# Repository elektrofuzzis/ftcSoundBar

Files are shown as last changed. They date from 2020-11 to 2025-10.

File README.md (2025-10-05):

# The ftcSoundBar Project

ftcSoundBar is a sound card for fischertechnik TXT4.0/TXT/TX-Controllers, Arduino, ftDuino and Raspeberry based on an [espressif LyraT](https://www.espressif.com/en/products/devkits/esp32-lyrat) board.

It has multiple connectors, so yit could be used in various configurations:
- wifi based WEB-UI
- wifi based RESTAPI
- I2C-bus Interface (TXT, TXT4.0)

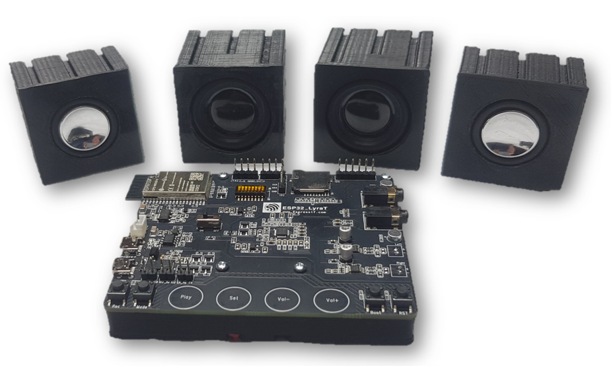
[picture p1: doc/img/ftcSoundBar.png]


*Please checkout the article about ftcSoundBar in [ft:pedia 4/2020](https://ftcommunity.de/ftpedia/2020/2020-4/ftpedia-2020-4.pdf#page=73") as well.*

## New version 1.4 available!

ftcSoundBar now supports TXT4.0-Controllers and RoboProCoding. Additionally, in I2C-mode the ftcSoundBar don't need a wifi any more.

## Quick start

In a first step, run the ftcSoundBar standalone - just playing some fancy musik.

ftcSoundBars's configuration and your musik files are stored on a SD card. Please format a SD Card as FAT32 and store some mp3-files in the root folder. Additionaly, please create a text file named ```ftcSoundBar.conf``` and store it in the root folder as well:

```
WIFI=1
WIFI_SSID=<SSID>
WIFI_PASSWORD=<Password>
TXT_AP_MODE=0
I2C_MODE=1
DEBUG=0
STARTUP_VOLUME=15
HOSTNAME=ftcSoundBar
```

Add your wifi's SSID and Password and plug the SD card in the ftcSoundBars SD card slot. 

Connect your speakers with the fischertechnik/Maerklin plugs at the right side of the device. Alternatively, you yould use headphones  at the ```PHONEJACK```.

There are two micro USB connectors ```POWER``` and ```UART``` at the left side of the board. Connect ```POWER``` to an USB charger - with at least 1A -.

The devices starts, the green LED between CPU and DIP switched will start flashing. After some seconds, flashing stops. Your device is now connected to your wifi.

*Notice: if your device don't stops flashing after some seconds, please check your SD-Card and wifi settings in your ftcSoundBar.conf file.*

Enter ```http://ftcSoundBar``` in your browser to access the webUI of the ftcSoundBar. Using the marked setup- and ftcSoundBar icons you can flip between the main and the configuration view:

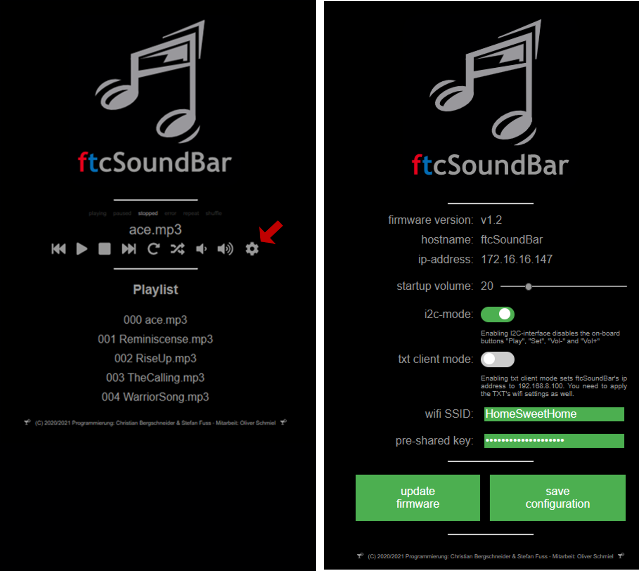
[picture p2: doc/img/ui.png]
main view


Try to play some songs on the main view.

*Notice: Maybe, you won't see the ```update firmware``` button in the configuration view. Don't worry  and read the firmware update section for more information.*

## Using your ftcSoundBar

Please check your prefreed controller and programm language. Follow up the links to get a short description how to use it.

| Controller | RoboProCoding | RoboPro | C++ | Phyton |
|:---:|:---:|:---:|:---:|:---:|
| TXT 4.0 | [i2c](./doc/ROBOProCoding-using-i2c-bus.md) | | | |
| TXT | | [i2c bus](./doc/ROBOPro-using-i²c-bus.md)<BR>[local wifi](./doc/ROBOPro-using-local-wifi.md)<BR>[TXT AP mode](./doc/ROBOPro-using-TXT's-AP-wifi-mode.md) | | [cfw](./doc/CFW-and-python-using-wifi.md) |
| TX | | [i2c bus](./doc/fischertechnik-TX.md) | | |
| ftDuino | | | [i2c bus](./doc/ftDuino.md) | |
| TX-PI | | | | [local wifi](./doc/TX-PI.md) |
| RaspberryPi | | | | [local wifi](./doc/Raspberry-Pi.md) |
| Arduino ATMEL | | | [i2c bus](./doc/ATMEL-based-Arduino-boards.md) | |
| ESP | | | [i2c bus](./doc/esp-32-family.md) | |

## Upgrade firmware

If you're upgrading the firmware the first time, please read the [firmware upgrade guide](./doc/Firmware-Upgrade.md).

Shortcut for experienced users:
- save `ftcSoundBar.bin` and `loader.bin`in the root folder of your SD card
- connect your ftcSoundBar to your local wifi
- Press `update firmware` button in the settings view

## Configuration File

| Option | Value | Description |
|:---:|:-----:|---|
| WIFI | 0..1 | 1 - use wifi | 0 - shutdown wifi |
| WIFI_SSID | <string> | SSID of your local wifi |
| WIFI_PASSWORD | <string> | Password of your local wifi |
| TXT_AP_MODE | 0..1 | In most cases 0<br>set it 1 to use the TXT AP option |
| I2C_MODE | 0..1 | 0 - off <br> 1 - on |
| DEBUG | 0..1 | In standard 0. 1 to get additional debug information in the console log. |
| STARTUP_VOLUME | 0..100 | Speaker volume after reseting the device. |
| HOSTNAME | <string> | Set a different hostname than ftcSoundBar. Just needed to run 2 devices in the same wifi |

## Build your own ftcSoundBar

This Chapter describes how to build up your own ftcSoundBar from scratch. If you prefer to work with a prebuild system, you could purchase one at [www.gundermann.org](http://www.gundermann.org/shop). If you have already a ftcSoundBar please continue with chapter 2.

- [Build Hardware](Build-your-own-ftcSoundBar-hardware)
- [Build Software](Build-the-software)

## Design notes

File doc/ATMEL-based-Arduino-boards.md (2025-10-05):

# Arduino using I2C and C++

Most Arduino controllers don't have a wifi card. So you need to work with i2C-bus. Since most of them are 5V controllers, you need to use a level shifter like [ftExtender](https://gundermann-software.de/produkt/ft-extender/) between your Ardiono and ftcSoundBar.

* Download `ftcSoundBar.zip` from this repo.
* Add this library to your Arduino IDE using Sketch/Include File/Add zip-library.
* Connect your Arduino's i2²c port with the 6 pin port of the ftExtender. Use a 1:1 ribbon cable to connect the 10 pin port of the ftExtender and ftcSoundBar. You could connect other i²c-devices with the same cable. Their bus addresses need to be different to 0x33, which is the ftcSoundBar's address.
* Checkout the example application via FILE/EXAMPLES/FTCSOUNDBAR/FTCSOUNDBARDUINO
* A detailed description of the Arduino API is described in ...

**Remarks:**
* See chapter 1 for a description of the ftcSoundBar's i²c connector.
* See ftExtender's documentation for a description of the i²c connectors.

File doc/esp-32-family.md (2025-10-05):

# ESP32 using i2c and C++

esp-32-controllers have an i²c-interface and an wifi interface as well. The actual implementation uses the i²c-inteface. But feel free to implement the wifi RESTapi.

* All GPIO-ports of your esp-32-controller could be used as i²C-interface. Connect SDA, SCL and GND with the ftcSoundBar i²c interface.
* You don't need a evel shifter, since both boards are based on 3.3V logic levels.
* Download `ftcSoundBar.zip` from this repo.
* Add this library to your Arduino IDE using Sketch/Include File/Add zip-library.
* You might add the correct SDA and SCL ports to the library.
* Checkout the example application via FILE/EXAMPLES/FTCSOUNDBAR/FTCSOUNDBARDUINO
* A detailed description of the Arduino API is described in ...

**Remarks:**
* See hardware description of the ftcSoundBar's i²c connector.

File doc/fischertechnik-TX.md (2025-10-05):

# TXT with ROBOPro using a I2C cable

The fischertechnik TX controller doesn't have a wifi card. So you need to work with a ribbon cable. Since TX is a 5V controller, you need to use a level shifter like [ftExtender](https://gundermann-software.de/produkt/ft-extender/) between TX and ftcSoundBar.

- Checkout `robopro` folder
- Try `ftcSoundBar_I2C_Example.rpp` to play some songs.
- Store `robopro/lib/ftcSoundBarI2C.rpp` in your ROBOPro's library folder, so you could use it in your own project.

*MAC-Users: `ftcSoundBarI2C.rpp` is working fine with Parallels and Wine.*.

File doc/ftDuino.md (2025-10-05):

# ftDuino using I2C and C++

The ftDuino controller doesn't have a wifi card. So you need to work with i2C-bus. Since ftDuino is a 5V controller, you need to use a level shifter like [ftExtender](https://gundermann-software.de/produkt/ft-extender/) etween ftDuino and ftcSoundBar.

* Download `ftcSoundBar.zip` from this repo.
* Add this library to your Arduino IDE using Sketch/Include File/Add zip-library.
* Connect ftDuino's i2²c port with the ftExtender using a 1:1 ribbon cable. Use another 1:1 ribbon cable to connect ftExtender and ftcSoundBar. You could connect other i²c-devices with the same cable. Their bus addresses need to be different to 0x33, which is the ftcSoundBar's address.
* Checkout the example application via FILE/EXAMPLES/FTCSOUNDBAR/FTCSOUNDBARDUINO
* A detailed description of the Arduino API is described in ...

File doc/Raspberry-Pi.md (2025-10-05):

# Raspberry PI using wifi & Phyton

Raspberry Pi users could use the python interface to program the ftcSoundBar:

* Download phython library fom this repo.
* Connect TX-PI and ftcSoundBar to your local wifi.
* Use the python library to write your code.

**Remarks:**

* The library is very general. So it's working fine on every computer, which has a wifi connection and a python Intepreter.
* The raspberry pi has a i²c-bus-interface. You could use this interface, too. But you need to implement the i²c api on your own.

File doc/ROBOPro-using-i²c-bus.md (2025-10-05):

# TXT controller using roboPro & I2C

To connect the ftcSoundBar via i²c-bus, you just need to connect a 1:1 ribbon cable between TXT extention port and ftcSoundBar's I2C interface at the right side. 

- Checkout `robopro` folder
- Try `ftcSoundBar_I2C_Example.rpp` to play some songs.
- Store `robopro/lib/ftcSoundBarI2C.rpp` in your ROBOPro's library folder, so you could use it in your own project.

*MAC-Users: `ftcSoundBarI2C.rpp` is working fine with Parallels and Wine.*

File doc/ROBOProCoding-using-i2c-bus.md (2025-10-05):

# TXT 4.0 controller using ROBOProCoding & I2C

To connect the ftcSoundBar via i²c-bus, you need [6-to-pin-adapter](https://www.fischerfriendswoman.de/index.php?p=7&sp=9#R7668al) and two 1:1 ribbon cables between TXT 4.0 extention port and ftcSoundBar's I2C interface at the right side. 

- Checkout `RoboProCoding` folder
- Try `ftcSoundBar.ft` to play some songs.

*The getter functions like getVolume are not stable, due to some I2C bus limitations in the used expressif framework. As a workaoud, you could store the last transferred value in a global variable and use it instead of calling the getter functions.*

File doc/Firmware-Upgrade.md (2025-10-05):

# Firmware Upgrade Guide

## Prerequisites

Download the files ftcSoundBar.bin and Loader.bin from GitHub.

Store both files on you ftcSoundBar's SD card.

Configure ftcSoundBar.conf to use wifi:

```
WIFI=1
WIFI_SSID=<SSID>
WIFI_PASSWORD=<Password>
TXT_AP_MODE=0
I2C_MODE=1
DEBUG=0
STARTUP_VOLUME=15
HOSTNAME=ftcSoundBar
```
Check the following parameters

- WIFI=1 - This parameter is new in version 1.4
- Fill WIFI_SSID with your wifi's name.
- Fill WIFI_PASSWORD with your wifi's password.
- TXT_AP_MODE=0
- HOSTNAME=ftcSoundBar

## Run the Upgrades

Plug the SD card  in your ftcSoundBar and press RESET.
Once the grenn LED stops blinking, the ftcSoundBar has connected to your wifi.
Enter ```http:\\ftcSoundBar``` in your browser:

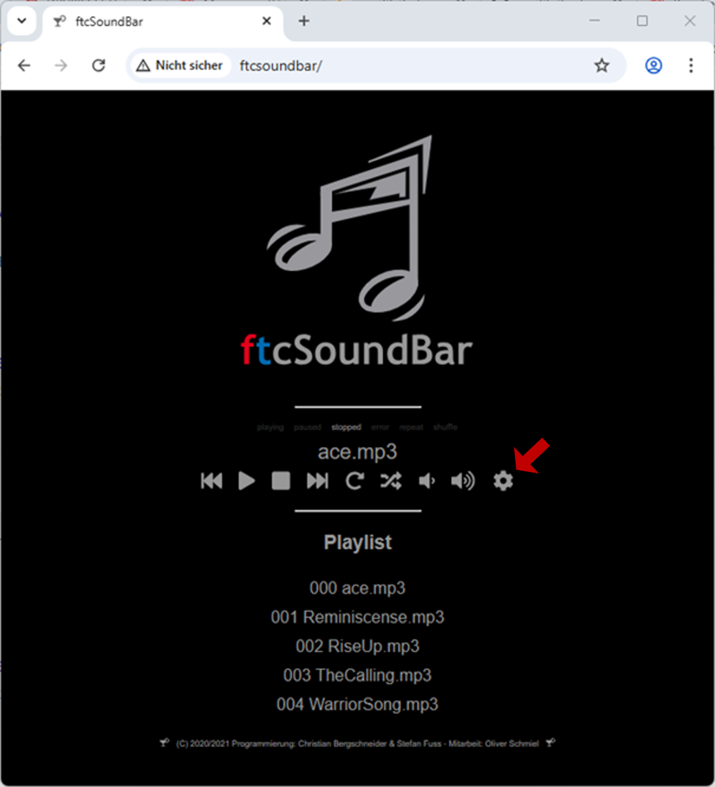
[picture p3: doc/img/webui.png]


Click the marked setup-button to change to the setup view:

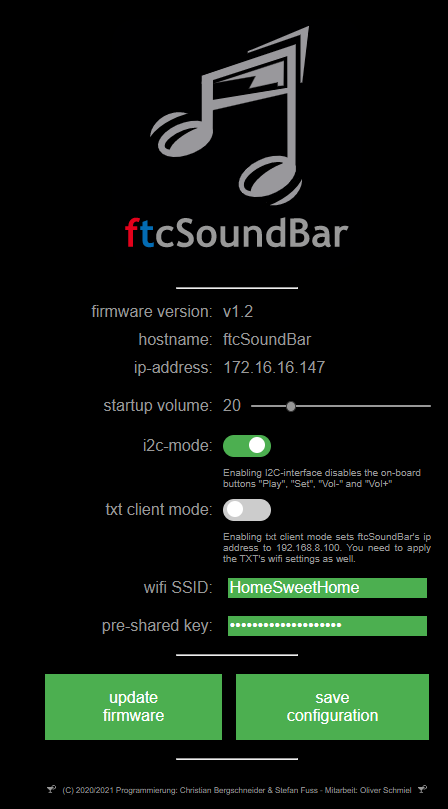
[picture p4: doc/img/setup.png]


With ```upgrade firmware``` you could now start the upgrade process.

During the upgrade, the green led flashes. Once it stops flashing, the firmware upgrade process succeeded. You could now call enter the ftcSoundBar in your browser again. Check the version number at the setup view.

*If you are missing the upgrade button, please check if both binary files ftcSoundBar.bin and loader.bin are stored at the SD card.*

## Follow up the upgrade porocess

Connect a USB cable to the UART port. You will now identify a new serial port at your PC.

Start a terminal program like putty and connect your serial interface with 115.200 Baud.

With clicking the update button, the process starts. In a first step ```loader.bin``` is flashed to the second partition:

```
I (25820) ftcSoundBar: Running partition type 0 subtype 16 (offset 0x00100000)
I (25830) ftcSoundBar: Writing to partition subtype 17 at offset 0x3b0000
I (25840) ftcSoundBar: data_read=1024
I (25850) ftcSoundBar: New firmware version: V1.31-dirty
I (25850) ftcSoundBar: Running firmware version: V1.31-dirty
I (26320) ftcSoundBar: esp_ota_begin succeeded
I (26340) ftcSoundBar: data_read=1024
I (26350) ftcSoundBar: data_read=1024

...

I (30130) ftcSoundBar: data_read=0
I (30130) ftcSoundBar: Total Write binary data length: 309760
I (30130) esp_image: segment 0: paddr=003b0020 vaddr=3f400020 size=11248h ( 70216) map
I (30170) esp_image: segment 1: paddr=003c1270 vaddr=3ffb0000 size=028f8h ( 10488)
I (30180) esp_image: segment 2: paddr=003c3b70 vaddr=40080000 size=0c4a8h ( 50344)
I (30210) esp_image: segment 3: paddr=003d0020 vaddr=400d0020 size=27b58h (162648) map
I (30280) esp_image: segment 4: paddr=003f7b80 vaddr=4008c4a8 size=03e5ch ( 15964)
I (30290) esp_image: segment 0: paddr=003b0020 vaddr=3f400020 size=11248h ( 70216) map
I (30330) esp_image: segment 1: paddr=003c1270 vaddr=3ffb0000 size=028f8h ( 10488)
I (30350) esp_image: segment 2: paddr=003c3b70 vaddr=40080000 size=0c4a8h ( 50344)
I (30370) esp_image: segment 3: paddr=003d0020 vaddr=400d0020 size=27b58h (162648) map
I (30440) esp_image: segment 4: paddr=003f7b80 vaddr=4008c4a8 size=03e5ch ( 15964)
I (30510) ftcSoundBar: Flashing firmware succeded.
I (30510) ftcSoundBar: Rebooting system in 5s
```

The loader now flashed the ftcSoundBar firmware to the other partition:

```
I (390) ftcSoundBar flash loader: **********************************************************************************************
I (400) ftcSoundBar flash loader: *                                                                                            *
I (410) ftcSoundBar flash loader: *                    Asymetric bootloader for flashing ftcSoundBar.bin.                      *
I (420) ftcSoundBar flash loader: *             (C) 2021 Oliver Schmiel, Christian Bergschneider & Stefan Fuss                 *
I (430) ftcSoundBar flash loader: *                                        Version v1.21                                       *
I (440) ftcSoundBar flash loader: *                                                                                            *
I (460) ftcSoundBar flash loader: * -> PLEASE BE PATIENT DRUING FLASH PROCESS. DON'T UNPLUG YOUR FTCSOUNDBAR UNTIL NOTICED! <- *
I (470) ftcSoundBar flash loader: *                                                                                            *
I (480) ftcSoundBar flash loader: **********************************************************************************************
I (490) ftcSoundBar flash loader:
I (500) ftcSoundBar flash loader: [1.0] Initialize peripherals management
I (510) ftcSoundBar flash loader: [1.1] Initialize and start peripherals
E (510) gpio: gpio_pullup_en(80): GPIO number error (input-only pad has no internal PU)
I (520) SDCARD: Using 1-line SD mode,  base path=/sdcard
I (530) AUDIO_THREAD: The esp_periph task allocate stack on internal memory
I (590) SDCARD: CID name SU02G!

I (1030) gpio: GPIO[22]| InputEn: 0| OutputEn: 0| OpenDrain: 0| Pullup: 1| Pulldown: 0| Intr:0
I (1030) ftcSoundBar flash loader: [2.0] Start flashing firmware
I (1030) ftcSoundBar flash loader: Running partition type 0 subtype 17 (offset 0x003b0000)
I (1040) ftcSoundBar flash loader: Writing to partition subtype 16 at offset 0x100000
I (1060) ftcSoundBar flash loader: data_read=1024
I (1060) ftcSoundBar flash loader: New firmware version: V1.31-dirty
I (1070) ftcSoundBar flash loader: Running firmware version: V1.31-dirty
I (3910) ftcSoundBar flash loader: esp_ota_begin succeeded
I (3930) ftcSoundBar flash loader: data_read=1024

...

I (21230) ftcSoundBar flash loader: data_read=0
I (21230) ftcSoundBar flash loader: Total Write binary data length: 1264224
I (21230) esp_image: segment 0: paddr=00100020 vaddr=3f400020 size=43ca8h (277672) map
I (21330) esp_image: segment 1: paddr=00143cd0 vaddr=3ffb0000 size=04344h ( 17220)
I (21340) esp_image: segment 2: paddr=0014801c vaddr=40080000 size=07ffch ( 32764)
I (21350) esp_image: segment 3: paddr=00150020 vaddr=400d0020 size=d2b04h (862980) map
I (21630) esp_image: segment 4: paddr=00222b2c vaddr=40087ffc size=11f08h ( 73480)
I (21660) esp_image: segment 0: paddr=00100020 vaddr=3f400020 size=43ca8h (277672) map
I (21750) esp_image: segment 1: paddr=00143cd0 vaddr=3ffb0000 size=04344h ( 17220)
I (21760) esp_image: segment 2: paddr=0014801c vaddr=40080000 size=07ffch ( 32764)
I (21780) esp_image: segment 3: paddr=00150020 vaddr=400d0020 size=d2b04h (862980) map
I (22060) esp_image: segment 4: paddr=00222b2c vaddr=40087ffc size=11f08h ( 73480)
I (22140) ftcSoundBar flash loader: Flashing firmware succeded.
I (22140) ftcSoundBar flash loader: Rebooting system in 5s
```

Afterwards the new firmware starts.

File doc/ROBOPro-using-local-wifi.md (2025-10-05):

# TXT with ROBOPro using a local wifi connection

In this configuration, you use the local wifi to send commands from your TXT controller to the ftcSoundBar. Since you already connected the ftcSoundBar to your local wifi during setup, it's a very simple way to program the ftcSoundBar. 

The wifi connection is nice, if you are working on a bigger projekt, because you don't need any cabling between TXT and ftcSoundBar at all.

**a) upload libftcSoundBar.so on your TXT controller**

First, you need to upload the `libftcSoundBar.so` library to your TXT controller. 
* Connect your TXT controller to your local wifi network using client mode (SETTINGS/NETWORK/WLAN/WLAN MODE/WLAN-CLIENT).
* Enable SSH DAEMON and WEB SERVER on your TXT controller (SETTINGS/SECURITY).
* Reboot your TXT controller.
* Start a browser and enter the TXT's IP address to connect to TXT's web server.
* The TXT will ask for simple authentification. Username is ROBOPro and and password is your TXT's serial number.
* The web site will display a directoy. Choose folder `libs`.
* Use button `upload files` to upload `libftcSoundBar.so` library into the `libs` folder.

If you get an write error while uploading the library, you need to change some rights on your TXT controller. This is a bug, dependend on your TXT's firmware version. You need to change the rights only one time:
* Connect to your TXT controller using a ssh client like  [putty](https://www.putty.org/).
* Username is ROBOPro, password is ROBOPro, too.
* Run `chmod 744 /opt/knobloch/libs`.

The step uploading the library is a little bit tricky. But never mind, you need to repeat this step after deploying a new firmware version only.

**b) Check ftcSoundBar**

* Connect the ftcSoundBar to your local wifi network as described in chapter 2.
* Use [http://ftcSoundBar](http://ftcSoundBar) to checkout your sound files track numbers. Since ROBOPro isn't able to handle strings, you need the track numbers to write your code.

**c) Working with ROBOPro**

* Download ftcSoundBarWifi.rpp and store it in your ROBOPro's library folder.
* Checkout the ROBOPro examples ftcSoundBarPlayer.rpp and ftcSoundBar_wifi_Example1.rpp
* A detailed description of the ROBOPro API is described in ...

The ROBOPro library is just a facade of the shared library `libftcSoundBar.so`. In standard wifi configuration, the library tries to access ftcSoundBar using it's DNS name `ftcSoundBar`, which is resolved by mDNS from the ftcSoundBar itself. Since TXT is connected to your local wifi and you already managed to access the ftcSoundBar's WEB UI, this procedure is very robust.

This procedure will fail, if ftcSoundBar and TXT controler are not connected to the same IP segment. In this case add the ftcSoundBar's ip-address to your local DNS controller or use the IP-commands in the robopro library.

**Remarks**

* MAC-Users: Please be aware, there a some limitations in using ROBOPro on a MAC. Wine won't work with this configuration at all, Parallels is fine but a little bit slow.
* Working with USB cable: You could connect your PC with the TXT using a USB cable as well. The TXT is able to be connected to multiple networks at on time (wifi to access ftcSoundBar and USB to conect to ROBOPro).
* Offline Mode is working fine, too.

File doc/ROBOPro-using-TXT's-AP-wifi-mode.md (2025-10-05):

# TXT with ROBOPro using a TXT in AP mode

Using the TXT's AP wifi mode is nearby the same procedure as using local wifi. The advantage of this mode is running your model on an exhibition or convention; you don't need any public wifi infrastructure.

* upload the library `libftcSoundBar.so` as described in 3.2.1.
* Change your TXT wifi settings to AP MODE.
* Connect to your ftcSoundBar's setup page, activate switch "TXT Client Mode", set TXT's SSID & password and save configuration.

Now you could access the ftcSoundBar from your TXT using the TXT's AP Mode. Please keep in mind, that you can't access to the WEB-UI of the ftcSoundBar from your PC any more. To access it, you need to connect your notebook to the TXT wifi, too. Since you might not get an ip-address assigned autmatically, you might setup a static ip-address on your PCs wifi card.

To connect the TXT from your PC, it's helpful to use the USB cable.

The ROBOPro library is the same as in local wifi mode. So all of your ROBOPro programs working in local wifi mode will run in AP mode, too.

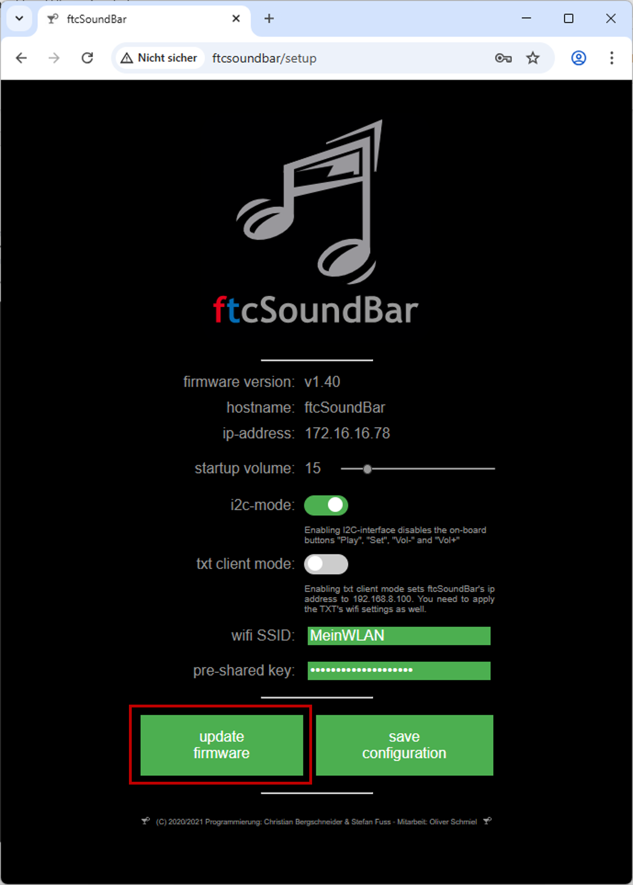
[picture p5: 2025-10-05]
doc/img/upgrade.png

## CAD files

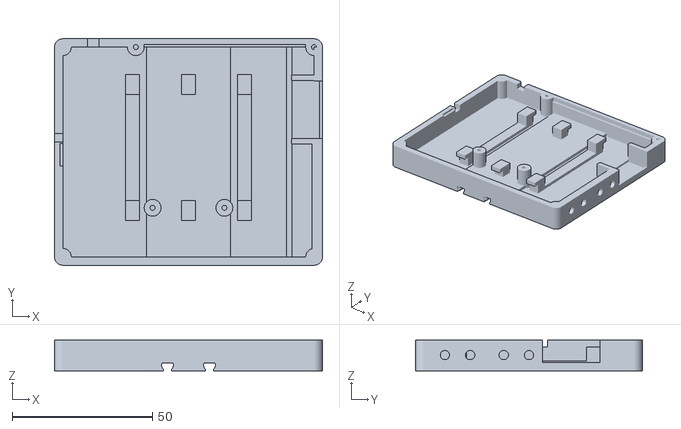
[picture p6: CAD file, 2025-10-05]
3D/ftcSoundBar_6v1a.stl
95.6 x 80.8 x 11.0

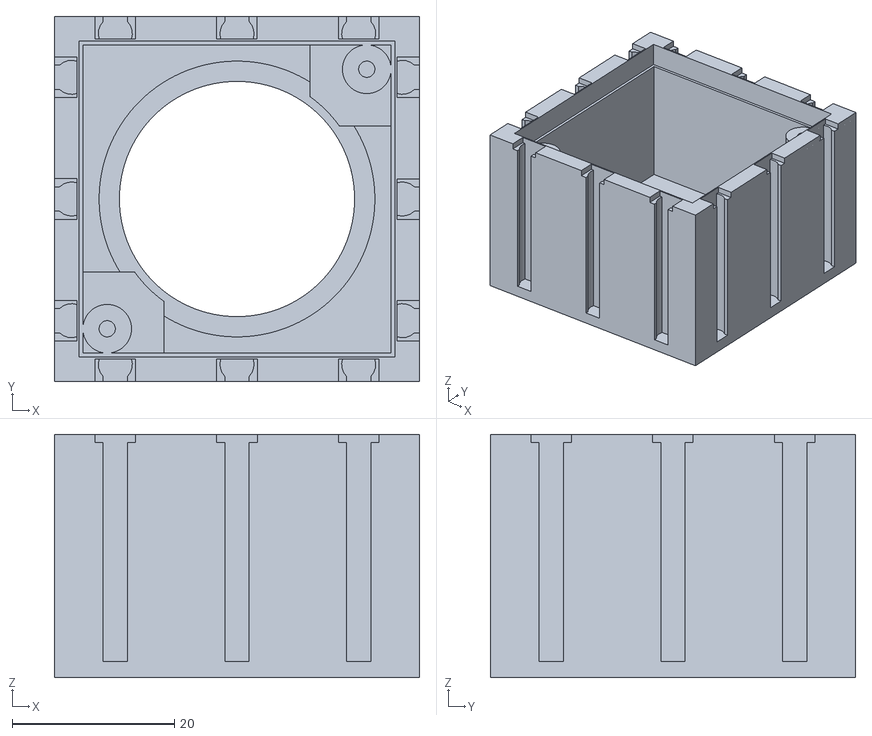
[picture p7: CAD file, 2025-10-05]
3D/box_pui_AS03104MR-N50-R_v14.stl
45.0 x 45.0 x 30.0

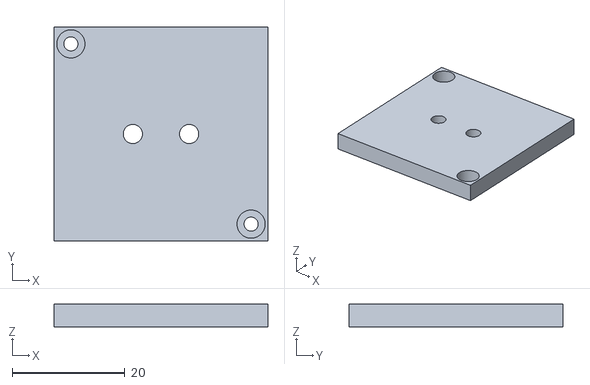
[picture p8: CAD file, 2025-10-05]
3D/box_rear_cover1v2.stl
38.0 x 38.0 x 4.00

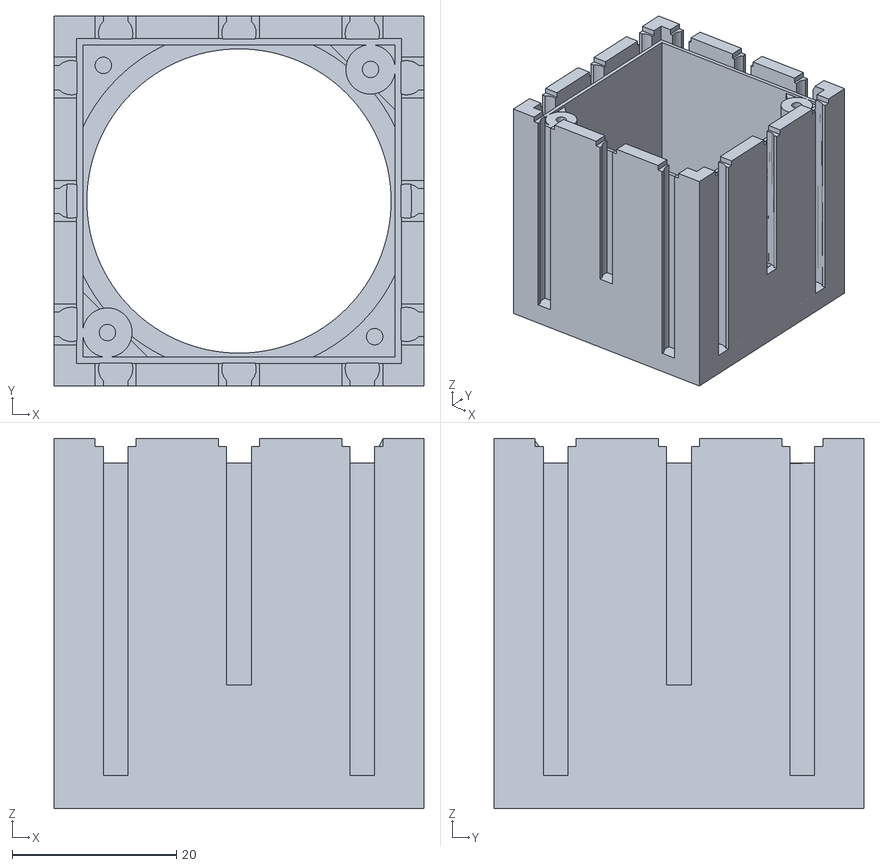
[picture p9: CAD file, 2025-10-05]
3D/box_gikfun_EK1794.stl
45.0 x 45.0 x 45.0

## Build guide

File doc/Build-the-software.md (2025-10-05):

# Build the Software

If you don't want, you don't need to build the software by your own. In every release, you could download the needed prebuild files.

The following text describes how to build your own release.

## ftcSoundBar's firmware

To flash the ftcSoundBar firmware the first time, you need to install some tools on your PC.

1. `git clone -b v5.2 https://github.com/espressif/esp-idf.git`
2. `cd esp-idf`
3. run `install.bat` on windows systems or `install.sh` on linux distributions
4. `git clone -b v2.7 https://github.com/espressif/esp-adf.git`
5. set in esp-idf/export.bat on windows Systems or export.sh on linux systems the variable ADF_PATH. Use the path, where you installed espadf.
6. `git clone https://github.com/elektrofuzzis/ftcSoundBar.git`
7. run `esp-idf/export.bat` or `esp-idf/export.sh` dependend on your OS.
8. `cd ftcSoundBar/firmware`
9. `idf.py build`
10. `idf.py flash`

## .so-library - TXT controller only

1. Download and install gcc compiler arm-linux-gnueabihf from <a href="https://www.linaro.org/downloads/">linareo<a>
2. `arm-linux-gnueabihf-gcc.exe -Ilib\gcc\arm-linux-gnueabihf\4.9.1\include -c -fpic -Wall libftcSoundBar.cpp`
3. `arm-linux-gnueabihf-gcc.exe -Ilib\gcc\arm-linux-gnueabihf\4.9.1\include -shared libftcSoundBar.o`

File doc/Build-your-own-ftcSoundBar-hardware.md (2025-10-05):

# Build your own Hardware

To build your own ftcSoundBar, you need a 3D printer and a soldering iron. If you don't have the needed equipment, you can purchase your ftcSoundBar at <a href="www.gundermann.org">http://www.gundermann.org/shop<a>

First, you need to organzize some components:
* 1 x <a href="https://www.espressif.com/en/products/devkits/esp32-lyrat">espressif LyraT</a>.
* 2 x <a href="https://www.puiaudio.com/products/as03104mr-n50-r">PUI audio speakers AS03104MR-N50-R</a>
* 1 x <a href="https://www.amphenol-icc.com/quickie-66506001lf.html">pin header / wire to board connecttor 10 positions"</a>
* 10 x tapping screws 2,2 x 4,5 mm
* 8 x <a href="https://www.fischerfriendswoman.de/index.php?p=7&sp=3#R7144">Bundhülse 8.4mm</a>
* 4 x cables with 2 cords (loud speakers)
* 1 x cable with 3 cords (i²c interface)

Download and print <a href="https://www.thingiverse.com/thing:4691172">speaker and ftcSoundBar case</a> at thingiverse

## ftcSoundBar

The lyraT board needs some simple modifications to get the I²C-connector and loud speaker connectors to the right side of the case:

<table>
<tr >
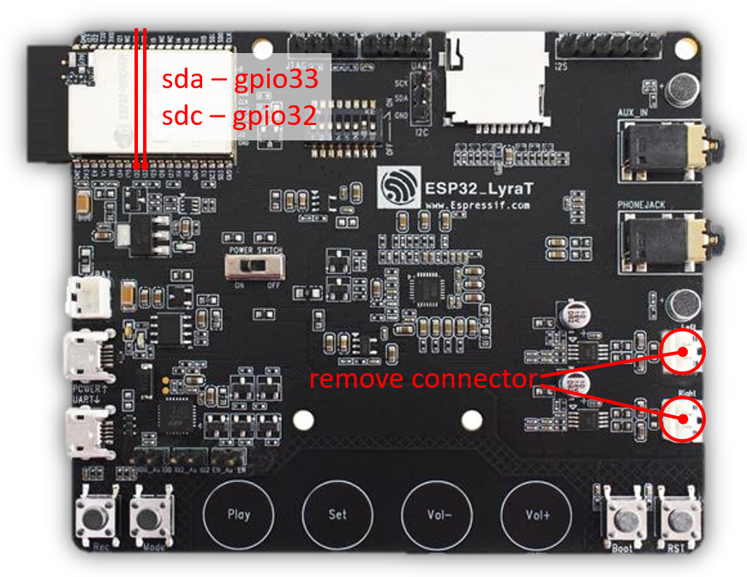
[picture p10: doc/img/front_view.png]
<td width="50%" height="300px"></td>
<td>At the front side of your LyraT board you need to remove the speaker connectors.<br><br>Add two cords of the i²c cable to GPIO32 and GPIO33 directly at the esp32-processor and fix it with some hot glue. The cables will be connected to the 10pos pin header in the ftcSoundBar case.</td></tr>

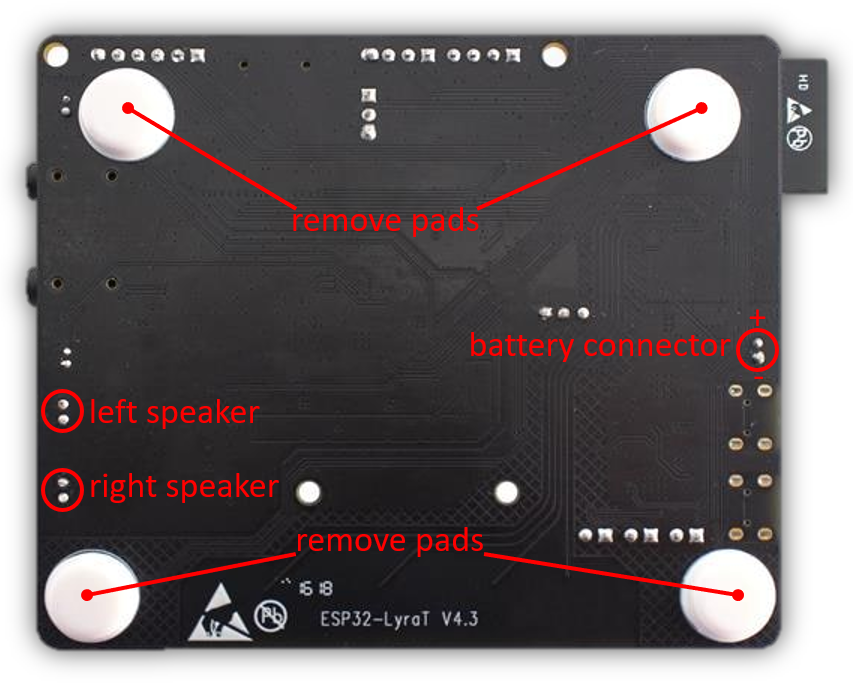
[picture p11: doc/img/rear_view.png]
<tr><td width="50%" height="300px"></td><td>Remove the 4 pads.<br><br>Add 2 loud speaker cables from the rear side to connect to the "Bundhülse" which will be glued in the ftcSoundBar case.<br><br>Connect the last cord of the i²c cable to the "-" pin of the battery connector.</td> </tr>

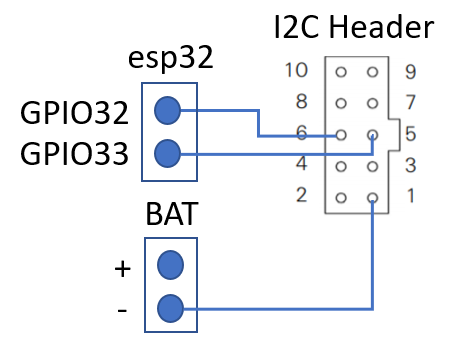
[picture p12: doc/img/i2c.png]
<tr><td width="50%" height="300px"></td>
<td>Connect the i²c cable to the 10 pos pin header as shown on the left side.<br><br>The pin header is compliant with the 3.3V fischertechnik-TXT extention port - pin 1 GND, pin 5 SDA, pin 6 SCL.
</td></tr>

</table>

## Speaker box

Setting up the boxes is quite easy:
* Connect a 2 cords cable to the loud speaker. 
* Plug two "Bundhülse" into the mounting pad and solder the cords.
* Set the loud speaker in the case by turning it to the left.
* Tight the mounting plate with a screw to the rear cap.
* Screw the rear cap with the box case.

<table>
<tr>
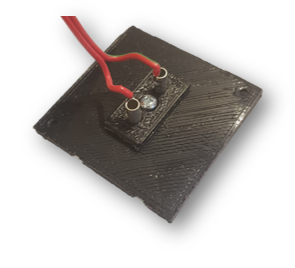
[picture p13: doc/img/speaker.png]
<td height="300px"></td>
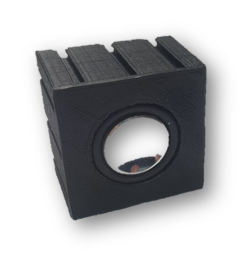
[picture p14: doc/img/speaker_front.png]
<td></td>
</tr>
</table>

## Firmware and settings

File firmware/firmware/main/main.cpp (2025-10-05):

/****************************************************************************************
 *
 * ftcSoundBar - a LyraT based fischertechnik compatible music box.
 *
 * Version 1.3
 *
 * (C) 2020 Oliver Schmied, Christian Bergschneider & Stefan Fuss
 *
 * Please run idf.py menuconfig, first
 *
 * EXAMPLE-CONFIGURATION: setting SSID & Password is helpful, but not mandatory
 * COMPONENT-CONFIGURATION/FAT FILESYSTEM SUPPORT: long filename support, UTF 8 encoding
 *
 ****************************************************************************************/

#define LOG_LOCAL_LEVEL ESP_LOG_DEBUG

#include <esp_wifi.h>
#include <esp_event.h>
#include <nvs_flash.h>
#include <esp_log.h>
#include <audio_element.h>
#include <esp_flash_partitions.h>
#include <esp_partition.h>
#include <esp_ota_ops.h>
#include <freertos/FreeRTOS.h>
#include <freertos/task.h>
#include <freertos/event_groups.h>
#include <input_key_service.h>
#include <string.h>
#include <sys/param.h>
#include <sys/unistd.h>
#include <esp_vfs.h>
#include <esp_http_server.h>
#include <cJSON.h>
#include <stdbool.h>
#include <mdns.h>
#include <esp_netif.h>
#include <periph_wifi.h>
#include <esp_task_wdt.h>

#include "adfcorrections.h"
#include "playlist.h"
#include "pipeline.h"
#include "ftcSoundBar.h"
#include "blink.h"
#include "ota.h"

extern "C" {
    void app_main(void);
}

#define FIRMWARE_VERSION "v1.40"

#define CONFIG_FILE "/sdcard/ftcSoundBar.conf"
static const char *TAG = "ftcSoundBar";
#define FIRMWAREUPDATE "/sdcard/ftcSoundBar.bin"
#define FIRMWARELOADER "/sdcard/loader.bin"

static EventGroupHandle_t wifi_event_group;
const int CONNECTED_BIT = BIT0;

#define FILE_PATH_MAX (ESP_VFS_PATH_MAX + 128)
#define SCRATCH_BUFSIZE (10240)

// I2C Slave Setup
#define _I2C_NUMBER(num) I2C_NUM_##num
#define I2C_NUMBER(num) _I2C_NUMBER(num)
#define I2C_SLAVE_NUM I2C_NUMBER(1)			        // 0 durch peripherals belegt
#define I2C_SLAVE_SCL_IO 32                         /*!< gpio number for i2c slave clock */
#define I2C_SLAVE_SDA_IO 33                         /*!< gpio number for i2c slave data */
#define I2C_DATA_LENGTH 512                         /*!< Data buffer length of test buffer */
#define I2C_SLAVE_TX_BUF_LEN (2 * I2C_DATA_LENGTH)  /*!< I2C slave tx buffer size */
#define I2C_SLAVE_RX_BUF_LEN (2 * I2C_DATA_LENGTH)  /*!< I2C slave rx buffer size */
#define I2C_SLAVE_ADDR 0x33

typedef struct http_server_context {
    char base_path[ESP_VFS_PATH_MAX + 1];
    char scratch[SCRATCH_BUFSIZE];
} http_server_context_t;

FtcSoundBar ftcSoundBar;

/*
esp_err_t audio_element_event_handler(audio_element_handle_t self, audio_event_iface_msg_t *event, void *ctx)
{
	return ftcSoundBar.pipeline.event_handler(self, event, ctx);
}
*/


/**************************************************************************************
 *
 * simple tasks
 *
 **************************************************************************************/


void task_reboot(void *pvParameter)
{
	ESP_LOGI( TAG, "I will reboot in 0.5s...");
	vTaskDelay(500 / portTICK_RATE_MS);
	esp_restart();

}

void task_blinky(void *pvParameter)
{

    /* Set the GPIO as a push/pull output */
    gpio_set_direction((gpio_num_t)BLINK_GPIO, GPIO_MODE_OUTPUT);
    while( 1 ) {
    	blink(250, 250 );
    }

}


void task_ota(void *pvParameter)
{

	ota( TAG, FIRMWARELOADER);

}

/******************************************************************
 *
 * WebServer
 *
 ******************************************************************/

/**
 * @brief send header of web site
 *
 * @param req
 *
 * @return error-code
 */
static esp_err_t send_header(httpd_req_t *req )
{
	extern const unsigned char header_start[] asm("_binary_header_html_start");
    extern const unsigned char header_end[]   asm("_binary_header_html_end");
    const size_t header_size = (header_end - header_start);
    httpd_resp_set_type(req, "text/html");
    httpd_resp_send_chunk(req, (const char *)header_start, header_size);
    return ESP_OK;
}


/**
 * @brief send favicon.ico
 *
 * @param req
 *
 * @return error-code
 */
static esp_err_t send_img(httpd_req_t *req )
{
	extern const unsigned char ftcSound_start[] asm("_binary_favicon_ico_start");
    extern const unsigned char ftcSound_end[]   asm("_binary_favicon_ico_end");
    const size_t ftcSound_size = (ftcSound_end - ftcSound_start);

    httpd_resp_set_type(req, "image/ico");
    httpd_resp_send_chunk(req, (const char *)ftcSound_start, ftcSound_size);
    return ESP_OK;
}

/**
 * @brief deliver favicon.ico
 *
 * @param req
 *
 * @return error-code
 */
static esp_err_t favico_get_handler(httpd_req_t *req )
{
	send_img(req);
    httpd_resp_sendstr_chunk(req, NULL);

	return ESP_OK;
}

typedef enum {
	IMAGE_LOGO,
	IMAGE_COCKTAIL,
	IMAGE_NEXT,
	IMAGE_PREVIOUS,
	IMAGE_PLAY,
	IMAGE_STOP,
	IMAGE_SHUFFLE,
	IMAGE_REPEAT,
	IMAGE_VOLUME_UP,
	IMAGE_VOLUME_DOWN,
	IMAGE_SETUP
} image_t;


esp_err_t httpd_resp_sendstr_chunk_cr(httpd_req_t *req, const char *line ) {

	char cr[10];

	httpd_resp_sendstr_chunk( req, line );

	sprintf(cr, "\n");
	httpd_resp_sendstr_chunk( req, cr);

	return ESP_OK;
}

esp_err_t httpd_resp_send_img(httpd_req_t *req, const char* prefix, image_t image, const char *postfix )
{
	httpd_resp_sendstr_chunk(req, prefix);

	if ( image == IMAGE_LOGO ) {
    	extern const unsigned char ftcSoundbar_start[] asm("_binary_ftcsoundbarlogo_svg_start");
		extern const unsigned char ftcSoundbar_end[]   asm("_binary_ftcsoundbarlogo_svg_end");
		const size_t ftcSoundbar_size = (ftcSoundbar_end - ftcSoundbar_start);
		httpd_resp_send_chunk(req, (const char *)ftcSoundbar_start, ftcSoundbar_size);

	} else if ( image == IMAGE_COCKTAIL ) {
		extern const unsigned char cocktail_start[] asm("_binary_cocktail_svg_start");
		extern const unsigned char cocktail_end[]   asm("_binary_cocktail_svg_end");
		const size_t cocktail_size = (cocktail_end - cocktail_start);
		httpd_resp_send_chunk(req, (const char *)cocktail_start, cocktail_size);

	} else if ( image == IMAGE_NEXT ) {
		extern const unsigned char next_start[] asm("_binary_next_svg_start");
		extern const unsigned char next_end[]   asm("_binary_next_svg_end");
		const size_t next_size = (next_end - next_start);
		httpd_resp_send_chunk(req, (const char *)next_start, next_size);

	} else if ( image == IMAGE_PLAY ) {
		extern const unsigned char play_start[] asm("_binary_play_svg_start");
		extern const unsigned char play_end[]   asm("_binary_play_svg_end");
		const size_t play_size = (play_end - play_start);
		httpd_resp_send_chunk(req, (const char *)play_start, play_size);

	} else if ( image == IMAGE_PREVIOUS ) {
		extern const unsigned char previous_start[] asm("_binary_previous_svg_start");
		extern const unsigned char previous_end[]   asm("_binary_previous_svg_end");
		const size_t previous_size = (previous_end - previous_start);
		httpd_resp_send_chunk(req, (const char *)previous_start, previous_size);

	} else if ( image == IMAGE_STOP ) {
		extern const unsigned char stop_start[] asm("_binary_stop_svg_start");
		extern const unsigned char stop_end[]   asm("_binary_stop_svg_end");
		const size_t stop_size = (stop_end - stop_start);
		httpd_resp_send_chunk(req, (const char *)stop_start, stop_size);

	} else if ( image == IMAGE_VOLUME_UP ) {
		extern const unsigned char volumeup_start[] asm("_binary_volumeup_svg_start");
		extern const unsigned char volumeup_end[]   asm("_binary_volumeup_svg_end");
		const size_t volumeup_size = (volumeup_end - volumeup_start);
		httpd_resp_send_chunk(req, (const char *)volumeup_start, volumeup_size);

	} else if ( image == IMAGE_VOLUME_DOWN ) {
		extern const unsigned char volumedown_start[] asm("_binary_volumedown_svg_start");
		extern const unsigned char volumedown_end[]   asm("_binary_volumedown_svg_end");
		const size_t volumedown_size = (volumedown_end - volumedown_start);
		httpd_resp_send_chunk(req, (const char *)volumedown_start, volumedown_size);

	} else if ( image == IMAGE_SHUFFLE ) {
		extern const unsigned char shuffle_start[] asm("_binary_shuffle_svg_start");
		extern const unsigned char shuffle_end[]   asm("_binary_shuffle_svg_end");
		const size_t shuffle_size = (shuffle_end - shuffle_start);
		httpd_resp_send_chunk(req, (const char *)shuffle_start, shuffle_size);

	} else if ( image == IMAGE_REPEAT ) {
		extern const unsigned char repeat_start[] asm("_binary_repeat_svg_start");
		extern const unsigned char repeat_end[]   asm("_binary_repeat_svg_end");
		const size_t repeat_size = (repeat_end - repeat_start);
		httpd_resp_send_chunk(req, (const char *)repeat_start, repeat_size);

	} else if ( image == IMAGE_SETUP ) {
		extern const unsigned char setup_start[] asm("_binary_setup_svg_start");
		extern const unsigned char setup_end[]   asm("_binary_setup_svg_end");
		const size_t setup_size = (setup_end - setup_start);
		httpd_resp_send_chunk(req, (const char *)setup_start, setup_size);

	} else {
		return ESP_FAIL;

	}

	httpd_resp_sendstr_chunk_cr(req, postfix);

	return ESP_OK;
}

/**
 * @brief deliver styles.css
 *
 * @param req
 *
 * @return error-code
 */
static esp_err_t styles_css_get_handler(httpd_req_t *req )
{
	extern const unsigned char styles_start[] asm("_binary_styles_css_start");
    extern const unsigned char styles_end[]   asm("_binary_styles_css_end");
    const size_t styles_size = (styles_end - styles_start);

    httpd_resp_set_type(req, "text/css");
    httpd_resp_send_chunk(req, (const char *)styles_start, styles_size);

	/* Send empty chunk to signal HTTP response completion */
    httpd_resp_sendstr_chunk(req, NULL);

    return ESP_OK;
}

/**
 * @brief send footer of web site
 *
 * @param req
 *
 * @return error-code
 */
static esp_err_t send_footer(httpd_req_t *req )
{
	/*
	extern const unsigned char footer_start[] asm("_binary_footer_html_start");
    extern const unsigned char footer_end[]   asm("_binary_footer_html_end");
    const size_t footer_size = (footer_end - footer_start);
    httpd_resp_set_type(req, "text/html");
    httpd_resp_send_chunk(req, (const char *)footer_start, footer_size);
    return ESP_OK;
    */

	httpd_resp_sendstr_chunk_cr(req, "<div class=\"small\">" );
	httpd_resp_sendstr_chunk_cr(req, "	<br />" );
	httpd_resp_send_img( req, "	<p>", IMAGE_COCKTAIL, " " );
	httpd_resp_sendstr_chunk_cr(req, "		&nbsp; (C) 2020/2021 Programmierung: Christian Bergschneider & Stefan Fuss - Mitarbeit: Oliver Schmiel &nbsp;");
	httpd_resp_send_img( req, "		", IMAGE_COCKTAIL, "</p>" );
	httpd_resp_sendstr_chunk_cr(req, "	<br />" );
	httpd_resp_sendstr_chunk_cr(req, "</div>" );
	httpd_resp_sendstr_chunk_cr(req, "</body>");
	httpd_resp_sendstr_chunk_cr(req, "</html>");

	return ESP_OK;
}


/**
 * @brief deliver html site setup
 *
 * @param req
 *
 * @return error-code
 */
static esp_err_t setup_html_get_handler(httpd_req_t *req )
{
	char line[512];
	char checked[20] = "";
	char display[30] = "";

	send_header(req);

	httpd_resp_sendstr_chunk_cr(req, "<table>" );
	httpd_resp_sendstr_chunk_cr(req, "	<tr height=\"20\"><td></td></tr>" );
	httpd_resp_send_img( req, "		<tr><td><a href=\"/\">", IMAGE_LOGO, "</a></td></tr>" );
	httpd_resp_sendstr_chunk_cr(req, "</table>" );

	httpd_resp_sendstr_chunk_cr(req, "<hr>" );

	// table with ftcSoundBar's settings
	httpd_resp_sendstr_chunk_cr(req, "<table align=\"center\">" );

	// Firmware Version
	sprintf(line, "	<tr><td style=\"text-align:right\" width=\"50%%\">firmware version:</td><td colspan=\"2\" style=\"text-align:left\">%s</td></tr>", FIRMWARE_VERSION );
	httpd_resp_sendstr_chunk_cr(req, line );

	// Hostname
	sprintf(line, "	<tr><td style=\"text-align:right\">hostname:</td><td colspan=\"2\" style=\"text-align:left\">%s</td></tr>", ftcSoundBar.HOSTNAME );
	httpd_resp_sendstr_chunk_cr(req, line );

	// IP Address
	esp_netif_ip_info_t ip_info;
	esp_netif_t *netif = esp_netif_get_handle_from_ifkey("WIFI_STA_DEF");
	esp_netif_get_ip_info(netif, &ip_info);
	sprintf(line, "	<tr><td style=\"text-align:right\">ip-address:</td><td colspan=\"2\" style=\"text-align:left\">" IPSTR "</td></tr>", IP2STR(&ip_info.ip) );
	
	// tcpip_adapter_ip_info_t myip;
	// tcpip_adapter_get_ip_info(TCPIP_ADAPTER_IF_STA, &myip);
	// sprintf(line, "	<tr><td style=\"text-align:right\">ip-address:</td><td colspan=\"2\" style=\"text-align:left\">%s</td></tr>", ip4addr_ntoa(&(myip.ip)));
	httpd_resp_sendstr_chunk_cr(req, line );

	// startup Volume
	sprintf(line, "	<tr><td style=\"text-align:right\" >startup volume:</td><td id=\"startup_volumeX\" style=\"text-align:left\" width=\"5%%\">%d</td><td width=\"45%%\"><input align=\"left\" onchange=\"vol_change();\" type=\"range\" min=\"0\" max=\"100\" value=\"%d\" class=\"volslider\" id=\"startup_volume\"></td></tr>", ftcSoundBar.STARTUP_VOLUME, ftcSoundBar.STARTUP_VOLUME );
	httpd_resp_sendstr_chunk_cr(req, line );

	// I2C
	if ( ftcSoundBar.I2C_MODE) {
		strcpy( checked, "checked");
		strcpy( display, "");
	} else {
		strcpy( checked, "");
		strcpy( display, "style=\"display:none\"");
	}
	sprintf( line, "	<tr><td style=\"text-align:right\">i2c-mode:</td><td colspan=\"2\" style=\"text-align:left\"><label class=\"switch\"><input type=\"checkbox\" id=\"i2c_mode\" %s><span class=\"slider round\"></span></label></td></tr>", checked);
	httpd_resp_sendstr_chunk_cr(req, line );
	httpd_resp_sendstr_chunk_cr(req, "	<tr><td style=\"text-align:right\">&nbsp;</td><td colspan=\"2\" style=\"font-size: 10px; text-align:left\">Enabling I2C-interface disables the on-board buttons \"Play\", \"Set\", \"Vol-\" and \"Vol+\"</td></tr>" );

	// TXT AP Mode
	if ( ftcSoundBar.TXT_AP_MODE) {
		strcpy( checked, "checked");
		strcpy( display, "");
	} else {
		strcpy( checked, "");
		strcpy( display, "style=\"display:none\"");
	}
	sprintf( line, "	<tr><td style=\"text-align:right\">txt client mode:</td><td colspan=\"2\" style=\"text-align:left\"><label class=\"switch\"><input type=\"checkbox\" id=\"txt_ap_mode\" %s><span class=\"slider round\"></span></label></td></tr>", checked);
	httpd_resp_sendstr_chunk_cr(req, line );
	httpd_resp_sendstr_chunk_cr(req, "	<tr><td style=\"text-align:right\">&nbsp;</td><td colspan=\"2\" style=\"font-size: 10px; text-align:justify\">Enabling txt client mode sets ftcSoundBar's ip address to 192.168.8.100. You need to apply the TXT's wifi settings as well.</td></tr>" );

	// SSID
	sprintf(line, "	<tr><td style=\"text-align:right\">wifi SSID:</td><td colspan=\"2\"><input type=\"text\" value=\"%s\" id=\"wifi_ssid\"></td></tr>", ftcSoundBar.WIFI_SSID );
	httpd_resp_sendstr_chunk_cr(req, line );

	// Password
	sprintf(line, "	<tr><td style=\"text-align:right\">pre-shared key:</td><td colspan=\"2\"><input type=\"password\" value=\"%s\" id=\"wifi_password\"></td></tr>", ftcSoundBar.WIFI_PASSWORD );
	httpd_resp_sendstr_chunk_cr(req, line );

	// Next Block
	httpd_resp_sendstr_chunk_cr(req, "</table>" );
	httpd_resp_sendstr_chunk_cr(req, "<hr>" );
	httpd_resp_sendstr_chunk_cr(req, "<table>" );

	// Buttons
	if ( ( access( FIRMWAREUPDATE, F_OK ) != -1 ) &&
         ( access( FIRMWARELOADER, F_OK ) != -1 ) ) {
		sprintf( line, "<tr><td><button type=\"button\" onclick=\"ota()\">update firmware</button></td><td><button type=\"button\" onclick=\"save_config('%s')\">save configuration</button></td></tr>", ftcSoundBar.HOSTNAME);
		httpd_resp_sendstr_chunk(req, line );
	} else {
		sprintf( line, "<tr><td colspan=\"2\"><button type=\"button\" onclick=\"save_config('%s')\">save configuration</button></td></tr>", ftcSoundBar.HOSTNAME);
		httpd_resp_sendstr_chunk(req, line );
	}

	httpd_resp_sendstr_chunk(req, "</table><hr>" );

	send_footer(req);

	/* Send empty chunk to signal HTTP response completion */
    httpd_resp_sendstr_chunk(req, NULL);

    return ESP_OK;
}
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
void app_main(void)
{
    esp_log_level_set("*", ESP_LOG_INFO);

	ESP_LOGI(TAG, "**********************************************************************************************");
	ESP_LOGI(TAG, "*                                                                                            *");
	ESP_LOGI(TAG, "*                                      ftcSoundBars                                           *");
	ESP_LOGI(TAG, "*  (C) 2021 Idee: Oliver Schmiel, Programmierung: Christian Bergschneider & Stefan Fuss      *");
	ESP_LOGI(TAG, "*                                        Version %s                                       *", FIRMWARE_VERSION);
	ESP_LOGI(TAG, "*                                                                                            *");
	ESP_LOGI(TAG, "**********************************************************************************************");
	ESP_LOGI(TAG, "");

	xTaskCreate(&task_blinky, "blinky", 2048, NULL, 5, &(ftcSoundBar.xBlinky) );

    nvs_flash_init();

    ESP_LOGI(TAG, "[1.0] Initialize peripherals management");
    esp_periph_config_t periph_cfg = DEFAULT_ESP_PERIPH_SET_CONFIG();
    esp_periph_set_handle_t set = esp_periph_set_init(&periph_cfg);

	gpio_reset_pin(BLINK_GPIO);
	gpio_set_direction(BLINK_GPIO, GPIO_MODE_OUTPUT);

    ESP_LOGI(TAG, "[1.1] Initialize and start peripherals");
    audio_board_sdcard_init(set, SD_MODE_1_LINE);

    ESP_LOGI(TAG, "[1.2] Set up a sdcard playlist and scan sdcard music save to it");
    ftcSoundBar.pipeline.playList.readDir( "/sdcard" );

    ESP_LOGI(TAG, "[1.3] read config file");
    ftcSoundBar.readConfigFile( (char *) CONFIG_FILE );
    if (ftcSoundBar.DEBUG) {
    	ESP_LOGI( TAG, "Set log level to debug.");
    	esp_log_level_set("*", ESP_LOG_DEBUG);
    }

    ESP_LOGI(TAG, "[2.0] Initialize wifi" );
	if (ftcSoundBar.WIFI) init_wifi();
	else ESP_LOGI(TAG, "     wifi is disabled.");

    ESP_LOGI(TAG, "[3.0] Start codec chip");
    ftcSoundBar.pipeline.StartCodec();
    ftcSoundBar.pipeline.build( FILETYPE_MP3 );

    if (ftcSoundBar.I2C_MODE) {

   	    ESP_LOGI(TAG, "[4.0] Start I2C Interface");
        ESP_ERROR_CHECK( i2c_slave_init() );

    } else {

    	ESP_LOGI(TAG, "[4.0] Create and start input key service");
        ESP_LOGI(TAG, "      Press the keys to control music player:");
        ESP_LOGI(TAG, "      [Play] to start, pause and resume, [Set] next song.");
        ESP_LOGI(TAG, "      [Vol-] or [Vol+] to adjust volume.");

        audio_board_key_init(set);
        input_key_service_info_t input_key_info[] = INPUT_KEY_DEFAULT_INFO();
    	input_key_service_cfg_t input_cfg = _INPUT_KEY_SERVICE_DEFAULT_CONFIG();
    	input_cfg.handle = set;
    	periph_service_handle_t input_ser = input_key_service_create(&input_cfg);
    	input_key_service_add_key(input_ser, input_key_info, INPUT_KEY_NUM);
    	periph_service_set_callback(input_ser, input_key_service_cb, (void *)ftcSoundBar.pipeline.getBoardHandle());

    }

    ESP_LOGI(TAG, "[5.0] Start Web Server");
    if (ftcSoundBar.WIFI) ESP_ERROR_CHECK( start_web_server( "localhost" ) );
	else ESP_LOGI(TAG, "     Web Server is disabled.");

    ESP_LOGI(TAG, "[6.0] Set volume");
    ftcSoundBar.pipeline.setVolume( ftcSoundBar.STARTUP_VOLUME );

    ESP_LOGI(TAG, "[7.0] Everything started");

    audio_event_iface_cfg_t evt_cfg = AUDIO_EVENT_IFACE_DEFAULT_CFG();
    audio_event_iface_handle_t evt = audio_event_iface_init(&evt_cfg);
    ftcSoundBar.pipeline.setListener( evt );

	if ( ftcSoundBar.xBlinky != NULL ) { vTaskDelete( ftcSoundBar.xBlinky ); }
	gpio_set_level(BLINK_GPIO, 1);

    // run forever
    while (1) {

    	if ( ftcSoundBar.I2C_MODE) { i2c_task(); };

    	// check on new song / repeat & shuffle
    	audio_event_iface_msg_t msg;
    	esp_err_t ret = audio_event_iface_listen(evt, &msg, 10);
    	if (ret == ESP_OK) { ftcSoundBar.pipeline.audioMessageHandler( msg ); }

    }

}

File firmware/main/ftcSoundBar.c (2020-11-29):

/****************************************************************************************
 *
 * ftcSoundBar - a LyraT based fischertechnik compatible music box.
 *
 * Version 0.1
 *
 * (C) 2020 Oliver Schmied, Christian Bergschneider & Stefan Fuss
 *
 * Please run idf.py menuconfig, first
 *
 * EXAMPLE-CONFIGURATION: setting SSID & Password is helpful, but not mandatory
 * COMPONENT-CONFIGURATION/FAT FILESYSTEM SUPPORT: long filename support, UTF 8 encoding
 *
 ****************************************************************************************/

#include "esp_wifi.h"
#include "esp_event_loop.h"
#include "nvs_flash.h"
#include "esp_http_client.h"
#include "esp_log.h"
#include "audio_pipeline.h"
#include "fatfs_stream.h"
#include "i2s_stream.h"
#include "mp3_decoder.h"
#include "filter_resample.h"
#include "esp_flash_partitions.h"
#include "esp_partition.h"
#include "esp_ota_ops.h"
#include "freertos/FreeRTOS.h"
#include "freertos/task.h"
#include "freertos/event_groups.h"
#include "input_key_service.h"
#include "sdcard_list.h"
#include "sdcard_scan.h"
#include <stdio.h>
#include <string.h>
#include <sys/param.h>
#include <sys/unistd.h>
#include <sys/stat.h>
#include <dirent.h>
#include "esp_vfs.h"
#include "esp_http_server.h"
#include "cJSON.h"
#include "esp_vfs_fat.h"
#include "sdmmc_cmd.h"
#include <stdbool.h>
#include "mdns.h"

#define FIRMWARE_VERSION "v1.0"

#define CONFIG_FILE "/sdcard/ftcSoundBar.conf"
static const char *TAG = "ftcSoundBar";
#define FIRMWAREUPDATE "/sdcard/ftcSoundBar.bin"

// some ftcSoundBar definitions
#define DEC_VOLUME -2
#define INC_VOLUME -1
#define MODE_SINGLE_TRACK 0
#define MODE_SHUFFLE 1
#define MODE_REPEAT 2

static EventGroupHandle_t wifi_event_group;
const int CONNECTED_BIT = BIT0;

#define BUFFSIZE 1024
static char ota_write_data[BUFFSIZE + 1] = { 0 };

#define BLINK_GPIO 22

#define FILE_PATH_MAX (ESP_VFS_PATH_MAX + 128)
#define SCRATCH_BUFSIZE (10240)

typedef struct http_server_context {
    char base_path[ESP_VFS_PATH_MAX + 1];
    char scratch[SCRATCH_BUFSIZE];
} http_server_context_t;

struct MusicBox {

	audio_board_handle_t board_handle;
	audio_pipeline_handle_t pipeline;
	audio_element_handle_t i2s_stream_writer, mp3_decoder, fatfs_stream_reader, rsp_handle;
	playlist_operator_handle_t sdcard_list_handle;
	uint8_t WIFI_SSID[32];
	uint8_t WIFI_PASSWORD[64];
	uint8_t TXT_AP_MODE;
	char HOSTNAME[64];

	uint16_t I2C_ADDRESS;
	int active_track, mode;
	TaskHandle_t xBlinky;

} ftcSoundBar;

void init_ftcSoundBar( void ) {
	ftcSoundBar.board_handle = NULL;
	ftcSoundBar.pipeline = NULL;
	ftcSoundBar.i2s_stream_writer = NULL;
	ftcSoundBar.mp3_decoder = NULL;
	ftcSoundBar.fatfs_stream_reader = NULL;
	ftcSoundBar.rsp_handle = NULL;
	ftcSoundBar.active_track = 0;
	ftcSoundBar.mode = MODE_SINGLE_TRACK;
	ftcSoundBar.xBlinky = NULL;

	memcpy( ftcSoundBar.WIFI_SSID, CONFIG_ESP_WIFI_SSID, 32 );
	memcpy( ftcSoundBar.WIFI_PASSWORD, CONFIG_ESP_WIFI_PASSWORD, 64 );
	ftcSoundBar.TXT_AP_MODE = 0;
	strcpy( ftcSoundBar.HOSTNAME, "ftcSoundBar" );
	ftcSoundBar.I2C_ADDRESS = 64;

}

/**************************************************************************************
 *
 * basic sd card functions
 *
 **************************************************************************************/

#define CONFTAG "CONFIG"

void write_config_file( void)
{
	FILE* f;

   	f = fopen(CONFIG_FILE, "w");

    if (f == NULL) {
    	ESP_LOGE(CONFTAG, "Could not write %s.", CONFIG_FILE);
    	return;
    }

    fprintf( f, "WIFI_SSID=%s\n", ftcSoundBar.WIFI_SSID);
    fprintf( f, "WIFI_PASSWORD=%s\n", ftcSoundBar.WIFI_PASSWORD);
    fprintf( f, "TXT_AP_MODE=%d\n", ftcSoundBar.TXT_AP_MODE);
    fprintf( f, "I2C_ADDRESS=%d\n", ftcSoundBar.I2C_ADDRESS);
    fprintf( f, "HOSTNAME=%s\n", ftcSoundBar.HOSTNAME);

    fclose(f);

}

void read_config_file( void )
{   FILE* f;

    struct stat st;
    if (stat(CONFIG_FILE, &st) == 0) {
    	// CONFIG_FILE exists, start reading it
    	f = fopen(CONFIG_FILE, "r");

    	if (f == NULL) {
    		ESP_LOGE(CONFTAG, "Could not read %s.", CONFIG_FILE);
    	    return;
    	}

    	char line[256];
    	char key[256];
    	char value[256];

    	while ( fscanf( f, "%s\n", line ) > 0 ) {
    		strcpy( key, strtok( line, "=" ) );
    		strcpy( value, strtok( NULL, "=" ) );

    		if ( strcmp( key, "WIFI_SSID" ) == 0 ) {

    			memcpy( ftcSoundBar.WIFI_SSID, value, 32 );

    		} else if ( strcmp( key, "WIFI_PASSWORD" ) == 0 ) {

    			memcpy( ftcSoundBar.WIFI_PASSWORD, value, 64 );

    		} else if ( strcmp( key, "TXT_AP_MODE" ) == 0 ) {

    		    ftcSoundBar.TXT_AP_MODE = ( atoi( value ) != 0 );

    		} else if ( strcmp( key, "I2C_ADDRESS" ) == 0 ) {

    			ftcSoundBar.I2C_ADDRESS = atoi( value );

    		} else if ( strcmp( key, "HOSTNAME" ) == 0 ) {

    			strcpy( ftcSoundBar.HOSTNAME, value );

    		} else {

    			ESP_LOGW(CONFTAG, "reading config file, ignoring pair (%s=%s)\n", key, value);
    		}

    	}

        fclose(f);

    } else {

    	// CONFIG_FILE is missing, create a sample file
    	ESP_LOGE(CONFTAG, "%s not found. Creating empty config file. Please set your parameters!", CONFIG_FILE);

    	write_config_file();

    }

}

/**************************************************************************************
 *
 * simple tasks
 *
 **************************************************************************************/


void task_reboot(void *pvParameter)
{
	ESP_LOGI( TAG, "I will reboot in 0.5s...");
	vTaskDelay(500 / portTICK_RATE_MS);
	esp_restart();

}

void task_blinky(void *pvParameter)
{

    gpio_pad_select_gpio(BLINK_GPIO);
    /* Set the GPIO as a push/pull output */
    gpio_set_direction(BLINK_GPIO, GPIO_MODE_OUTPUT);
    while( 1 ) {
        /* Blink off (output low) */
        gpio_set_level(BLINK_GPIO, 0);
        vTaskDelay(250 / portTICK_RATE_MS);
        /* Blink on (output high) */
        gpio_set_level(BLINK_GPIO, 1);
        vTaskDelay(250 / portTICK_RATE_MS);
    }

}

#define OTATAG "OTA"

static void __attribute__((noreturn)) task_fatal_error()
{
    ESP_LOGE(OTATAG, "Exiting task due to fatal error...");
    (void)vTaskDelete(NULL);

    while (1) {
        ;
    }
}
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

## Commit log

2020-11-29 Version 1.0
    [partitions.csv]
2021-01-10 Version 1.1
    [BAD WIFI]
    Optimierung auf schlechte wifi-Umgebungen
    [BROWSER]
    Warnings/Fehlermeldungen von FIREFOX und CHROME wurden analysiert und abgestellt.
    [IMAGES]
    SVGs werden inline im html Quelltext gesendet, so dass diese im Firefox immer korrekt angezeigt werden
    Das Logo wird als inline svg übertragen.
    Auf dem Logo liegt bei der normalen Seite kein Link mehr auf sich selbst.
    [FORMATE]
    Angezeigte Dateiformate sind MP3 und WAV
    [HTML-AUSGABE]
    Ausgabe von / wurde überarbeitet, so dass der HTML-Text lesbar ist
    [PIPELINE]
    Die Audio-Pipeline wurde refactored, so dass hier keine Memory Leaks mehr enstehen
    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
    [ftcSoundBar.cpp, ftcSoundBar.h, main.cpp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]
2021-01-26 Version 1.2
    [UI]
    Darstellung playing/pasue wurde korrigiert.
    [SETUP]
    Dialog wurde überarbeitet.
    Es können nun die Lautstärke nach dem Hochfahren des Gerätes eingestellt und der I2C-Moduseingeschaltet werden.
    [I2C]
    Die ftcSoundBar kann jetzt auch über I2C Bus angesteuert werden.
    [MODE]
    Wird der Modus durch die API oder die UI gesetzt, so wird der aktuele Track nicht mehr automatisch gestartet.
    [ftcSoundBar.cpp, ftcSoundBar.h, main.cpp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]
2021-01-31 Arduino interface library
2021-02-21 Version 1.31
    - asymetric ota partitions
    - stability fixes
    - loader
    [partitions.csv]
2025-10-05 feat: RoboProCoding & TXT 4.0 support
    [box_gikfun_EK1794.stl, box_pui_AS03104MR-N50-R_v14.stl, box_rear_cover1v2.stl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]
